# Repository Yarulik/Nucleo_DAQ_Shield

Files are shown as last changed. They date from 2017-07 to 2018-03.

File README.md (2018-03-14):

# Nucleo DAQ Shield
The Nucleo DAQ Shield mixed signal PCB that houses connectors and auxiliary circuitry (buffers, H-bridge, voltage regulators). It allows the STM32 microcontroller to interface with the [Analog Frontend](https://github.com/ColumbiaOpenSourceUltrasound/Analog_Frontend), motor, and other sensors.

### Drawings
Schematic:  
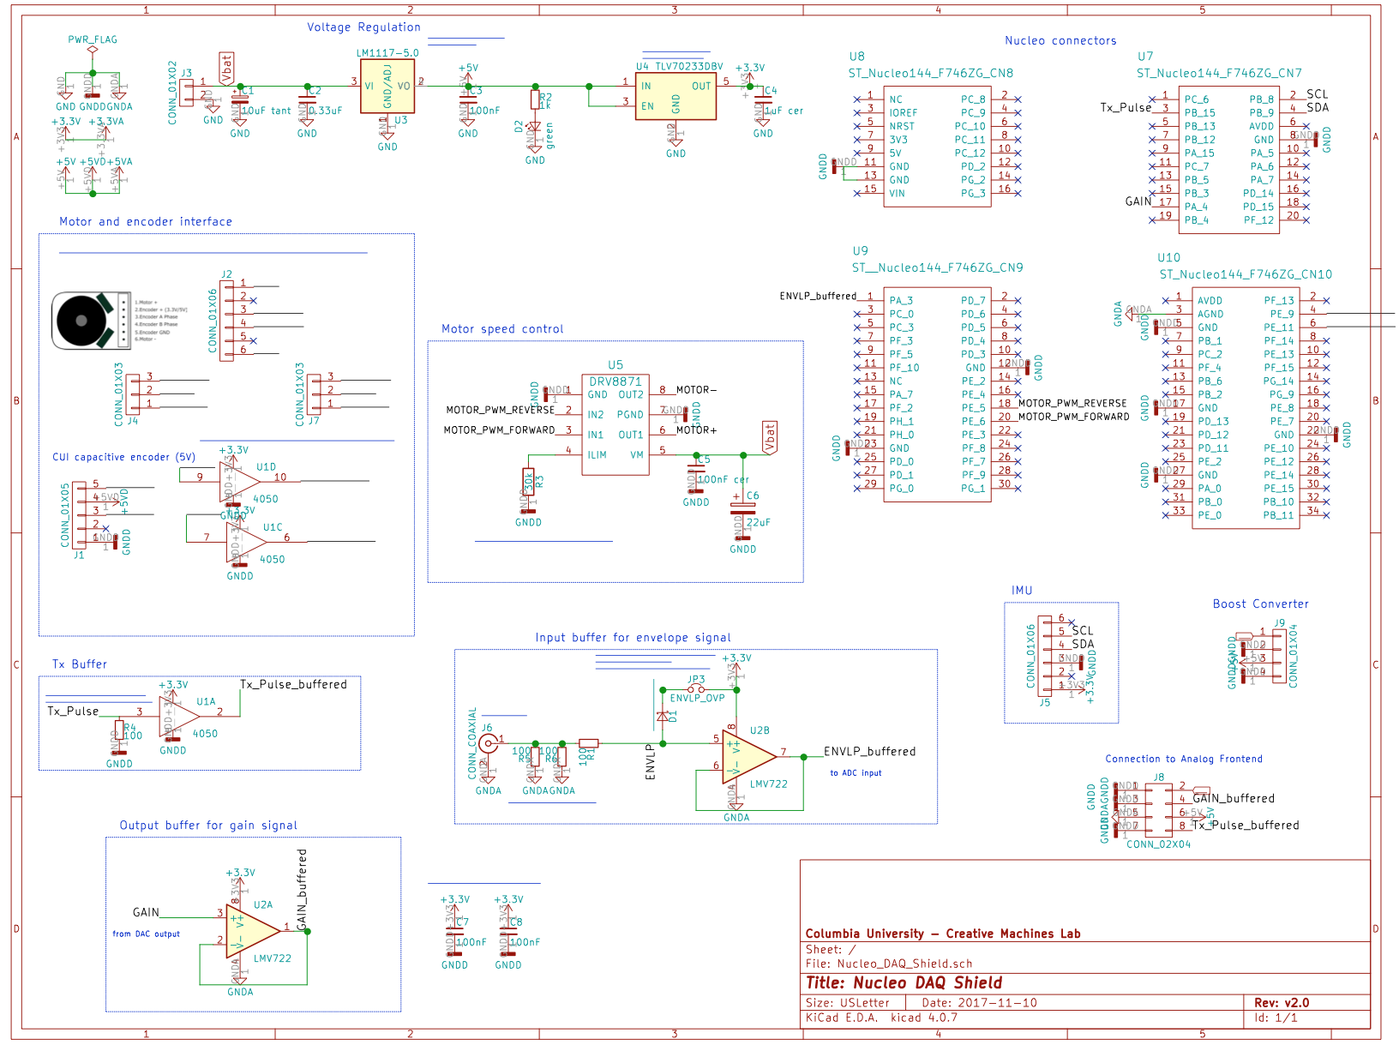
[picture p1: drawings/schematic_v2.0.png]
Schematic
  
See the `drawings` folder for a high-resolution PDF version.

PCB:  
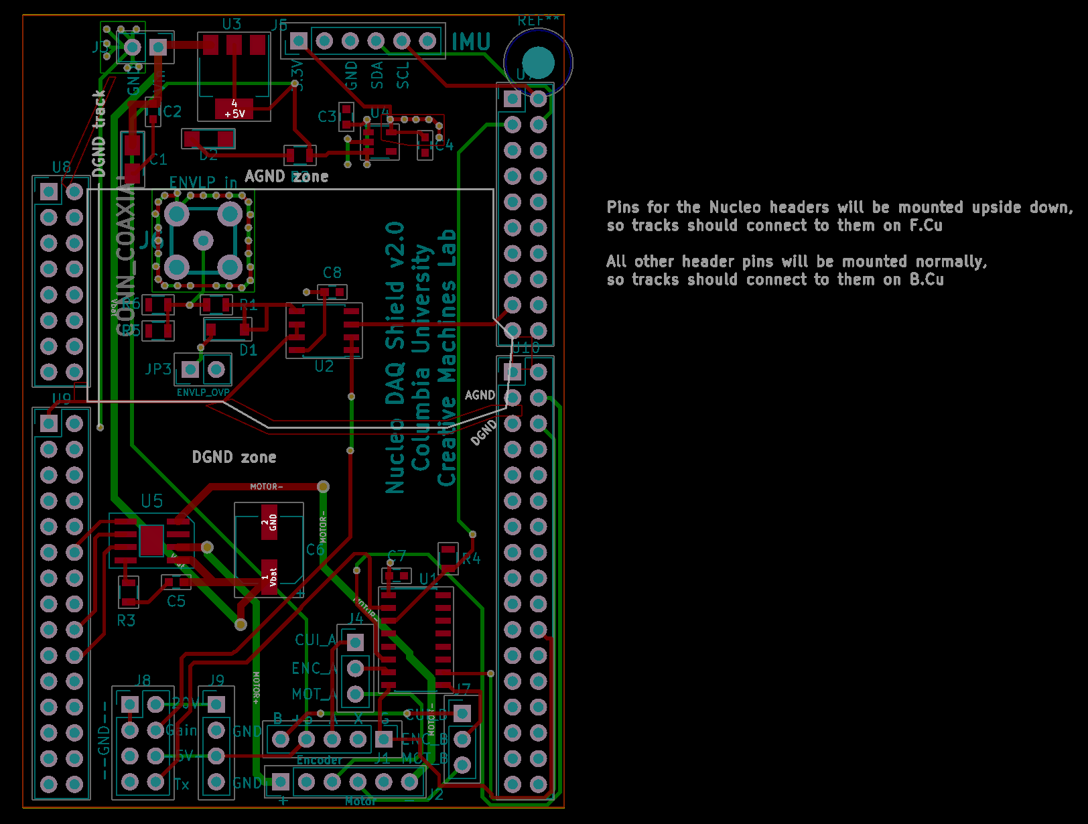
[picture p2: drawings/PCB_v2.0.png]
PCB
  
See the `drawings` folder for a full resolution PDF version, including each layer individually. 

3D view:  
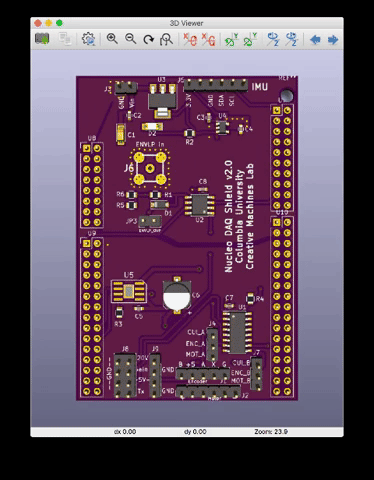
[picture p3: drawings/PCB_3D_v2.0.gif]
3D PCB


### Bill of Materials
See `Nucleo_DAQ_Shield.html`.

### Changelog
* `v1.0` Initial design.
* `v1.2` 
* `v1.3` Changed dimensions to improve manufacturability.
* `v2.0` Replaced several components; added connector for IMU and jumpers to switch between internal/external encoder.

### Credits
Designed by William Meng and Ruoyu Sheng.

The motor control circuitry was adapted from the [Adafruit DRV8871 breakout board](https://learn.adafruit.com/adafruit-drv8871-brushed-dc-motor-driver-breakout/download).

The [Arduino Shield module](https://www.thingiverse.com/thing:9630) by nicholasclewis helped with aligning the header pins.

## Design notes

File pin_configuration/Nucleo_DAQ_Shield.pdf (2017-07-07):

## Nucleo_DAQ_Shield Project Configuration Report

# 1. Description

## 1.1. Project

Project Name | Nucleo_DAQ_Shield
Board Name | No information
Generated with: | STM32CubeMX 4.21.0
Date | 07/07/2017

## 1.2. MCU

MCU Series | STM32F7
MCU Line | STM32F7x6
MCU name | STM32F746ZGTx
MCU Package | LQFP144
MCU Pin number | 144

# 2. Pinout Configuration

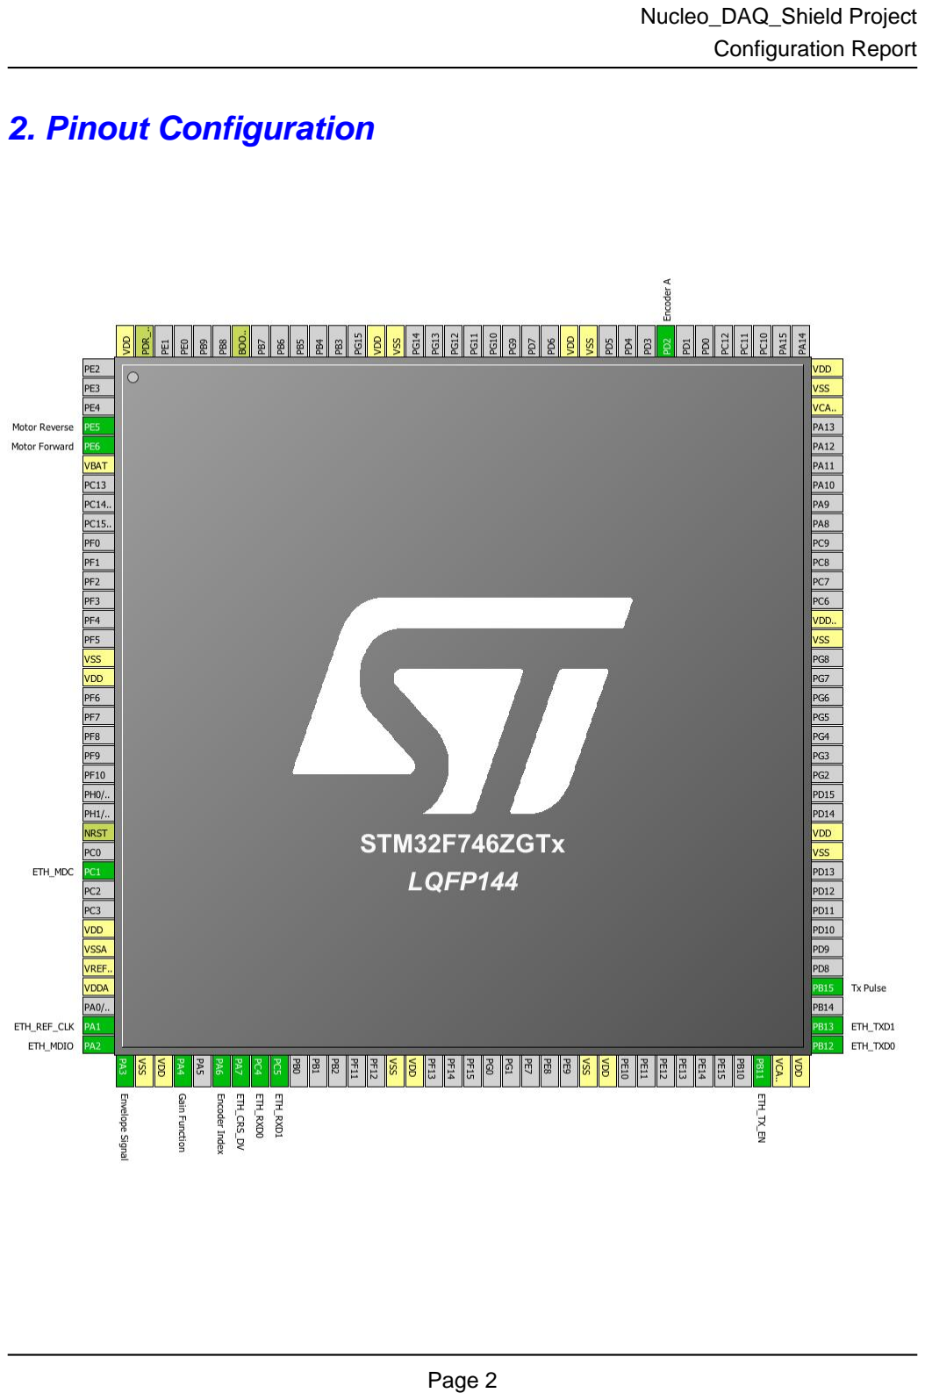
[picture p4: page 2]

# 3. Pins Configuration

Pin Number LQFP144 | Pin Name (function after reset) | Pin Type | Alternate Function(s) | Label
4 | PE5 | I/O | TIM9_CH1 | Motor Reverse
5 | PE6 | I/O | TIM9_CH2 | Motor Forward
6 | VBAT | Power
16 | VSS | Power
17 | VDD | Power
25 | NRST | Reset
27 | PC1 | I/O | ETH_MDC
30 | VDD | Power
31 | VSSA | Power
32 | VREF+ | Power
33 | VDDA | Power
35 | PA1 | I/O | ETH_REF_CLK
36 | PA2 | I/O | ETH_MDIO
37 | PA3 | I/O | ADC1_IN3, ADC2_IN3, ADC3_IN3 | Envelope Signal
38 | VSS | Power
39 | VDD | Power
40 | PA4 | I/O | DAC_OUT1 | Gain Function
42 | PA6 | I/O | TIM3_CH1 | Encoder Index
43 | PA7 | I/O | ETH_CRS_DV
44 | PC4 | I/O | ETH_RXD0
45 | PC5 | I/O | ETH_RXD1
51 | VSS | Power
52 | VDD | Power
61 | VSS | Power
62 | VDD | Power
70 | PB11 | I/O | ETH_TX_EN
71 | VCAP_1 | Power
72 | VDD | Power
73 | PB12 | I/O | ETH_TXD0
74 | PB13 | I/O | ETH_TXD1
76 | PB15 | I/O | TIM12_CH2 | Tx Pulse
83 | VSS | Power
84 | VDD | Power
94 | VSS | Power
95 | VDDUSB | Power

Pin Number LQFP144 | Pin Name (function after reset) | Pin Type | Alternate Function(s) | Label
106 | VCAP_2 | Power
107 | VSS | Power
108 | VDD | Power
116 | PD2 | I/O | TIM3_ETR | Encoder A
120 | VSS | Power
121 | VDD | Power
130 | VSS | Power
131 | VDD | Power
138 | BOOT0 | Boot
143 | PDR_ON | Reset
144 | VDD | Power

# 4. Clock Tree Configuration

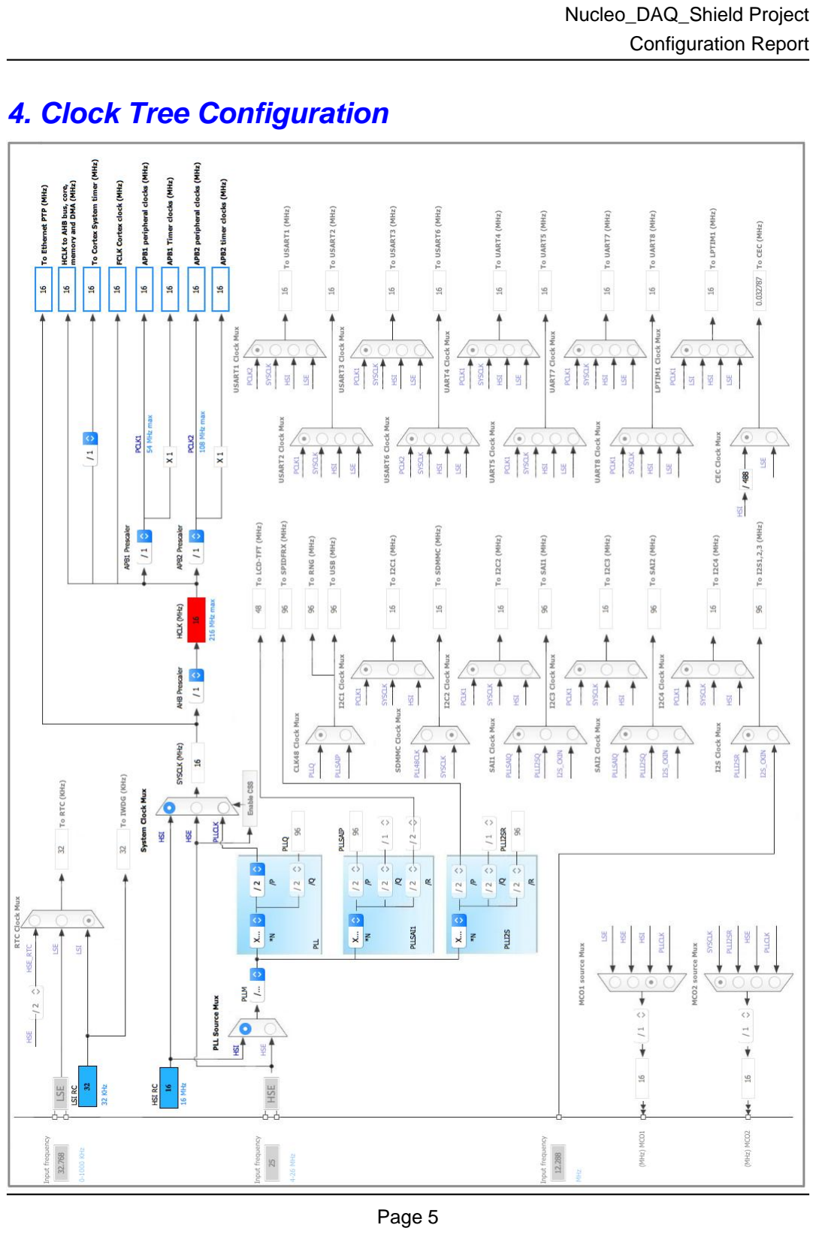
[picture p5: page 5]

# 5. IPs and Middleware Configuration

# 5.1. ADC1

## mode: IN3

## 5.1.1. Parameter Settings:

### ADCs_Common_Settings:

Mode | Independent mode

### ADC_Settings:

Clock Prescaler | PCLK2 divided by 2
Resolution | 12 bits (15 ADC Clock cycles)
Data Alignment | Right alignment
Scan Conversion Mode | Disabled
Continuous Conversion Mode | Disabled
Discontinuous Conversion Mode | Disabled
DMA Continuous Requests | Disabled
End Of Conversion Selection | EOC flag at the end of single channel conversion

### ADC_Regular_ConversionMode:

Number Of Conversion | 1
External Trigger Conversion Source | Regular Conversion launched by software
External Trigger Conversion Edge | None
Rank | 1
Channel | Channel 3
Sampling Time | 3 Cycles

### ADC_Injected_ConversionMode:

Number Of Conversions | 0

### WatchDog:

Enable Analog WatchDog Mode | false

# 5.2. ADC2

## mode: IN3

## 5.2.1. Parameter Settings:

### ADCs_Common_Settings:

Mode | Independent mode

### ADC_Settings:

Clock Prescaler | PCLK2 divided by 2
Resolution | 12 bits (15 ADC Clock cycles)
Data Alignment | Right alignment
Scan Conversion Mode | Disabled
Continuous Conversion Mode | Disabled
Discontinuous Conversion Mode | Disabled
DMA Continuous Requests | Disabled
End Of Conversion Selection | EOC flag at the end of single channel conversion

### ADC_Regular_ConversionMode:

Number Of Conversion | 1
External Trigger Conversion Source | Regular Conversion launched by software
External Trigger Conversion Edge | None
Rank | 1
Channel | Channel 3
Sampling Time | 3 Cycles

### ADC_Injected_ConversionMode:

Number Of Conversions | 0

### WatchDog:

Enable Analog WatchDog Mode | false

# 5.3. ADC3

## mode: IN3

## 5.3.1. Parameter Settings:

### ADCs_Common_Settings:

Mode | Independent mode

### ADC_Settings:

Clock Prescaler | PCLK2 divided by 2
Resolution | 12 bits (15 ADC Clock cycles)
Data Alignment | Right alignment
Scan Conversion Mode | Disabled
Continuous Conversion Mode | Disabled
Discontinuous Conversion Mode | Disabled
DMA Continuous Requests | Disabled
End Of Conversion Selection | EOC flag at the end of single channel conversion

### ADC_Regular_ConversionMode:

Number Of Conversion | 1
External Trigger Conversion Source | Regular Conversion launched by software
External Trigger Conversion Edge | None
Rank | 1
Channel | Channel 3
Sampling Time | 3 Cycles

### ADC_Injected_ConversionMode:

Number Of Conversions | 0

### WatchDog:

Enable Analog WatchDog Mode | false

# 5.4. DAC

## mode: OUT1 Configuration

## 5.4.1. Parameter Settings:

### DAC Out1 Settings:

Output Buffer | Enable
Trigger | None

# 5.5. ETH

## Mode: RMII

## 5.5.1. Parameter Settings:

### Advanced : Ethernet Media Configuration:

Auto Negotiation | Enabled

### General : Ethernet Configuration:

Ethernet MAC Address | 00:80:E1:00:00:00
PHY Address | 1

### Ethernet Basic Configuration:

Rx Mode | Polling Mode
TX IP Header Checksum Computation | By hardware

## 5.5.2. Advanced Parameters:

### External PHY Configuration:

PHY | LAN8742A_PHY_ADDRESS
PHY Address Value | 1
PHY Reset delay these values are based on a 1 ms Systick interrupt | 0x000000FF *
PHY Configuration delay | 0x00000FFF *
PHY Read TimeOut | 0x0000FFFF *
PHY Write TimeOut | 0x0000FFFF *

### Common : External PHY Configuration:

Transceiver Basic Control Register | 0x00 *
Transceiver Basic Status Register | 0x01 *
PHY Reset | 0x8000 *
Select loop-back mode | 0x4000 *
Set the full-duplex mode at 100 Mb/s | 0x2100 *
Set the half-duplex mode at 100 Mb/s | 0x2000 *
Set the full-duplex mode at 10 Mb/s | 0x0100 *
Set the half-duplex mode at 10 Mb/s | 0x0000 *
Enable auto-negotiation function | 0x1000 *
Restart auto-negotiation function | 0x0200 *
Select the power down mode | 0x0800 *
Isolate PHY from MII | 0x0400 *
Auto-Negotiation process completed | 0x0020 *
Valid link established | 0x0004 *
Jabber condition detected | 0x0002 *

### Extended : External PHY Configuration:

PHY special control/status register Offset | 0x10 *
PHY Speed mask | 0x0002 *
PHY Duplex mask | 0x0004 *
PHY Interrupt Source Flag register Offset | 0x000B *
PHY Link down inturrupt | 0x000B *

# 5.6. SYS

## Timebase Source: SysTick

# 5.7. TIM3

## Trigger Source: TI1_ED Clock Source : ETR2

## 5.7.1. Parameter Settings:

### Counter Settings:

Prescaler (PSC - 16 bits value) | 0
Counter Mode | Up
Counter Period (AutoReload Register - 16 bits value ) | 0
Internal Clock Division (CKD) | No Division
auto-reload preload | Disable
Slave Mode Controller | Slave mode disable

### Trigger Output (TRGO) Parameters:

Master/Slave Mode | Disable (no sync between this TIM (Master) and its Slaves
Trigger Event Selection TRGO | Reset (UG bit from TIMx_EGR)

### Clock:

Clock Filter (4 bits value) | 0
Clock Polarity | non inverted
Clock Prescaler | Prescaler not used

### Trigger:

Trigger Filter (4 bits value) | 0

# 5.8. TIM9

## mode: Clock Source Channel1: PWM Generation CH1 Channel2: PWM Generation CH2

## 5.8.1. Parameter Settings:

### Counter Settings:

Prescaler (PSC - 16 bits value) | 0
Counter Mode | Up
Counter Period (AutoReload Register - 16 bits value ) | 0
Internal Clock Division (CKD) | No Division
auto-reload preload | Disable

### Clear Input:

Clear Input Source | Disable

### PWM Generation Channel 1:

Mode | PWM mode 1
Pulse (16 bits value) | 0
Fast Mode | Disable
CH Polarity | High

### PWM Generation Channel 2:

Mode | PWM mode 1
Pulse (16 bits value) | 0
Fast Mode | Disable
CH Polarity | High

# 5.9. TIM12

## Channel2: PWM Generation CH2

## 5.9.1. Parameter Settings:

### Counter Settings:

Prescaler (PSC - 16 bits value) | 0
Counter Mode | Up
Counter Period (AutoReload Register - 16 bits value ) | 0
Internal Clock Division (CKD) | No Division
auto-reload preload | Disable

### Clear Input:

Clear Input Source | Disable

### PWM Generation Channel 2:

Mode | PWM mode 1
Pulse (16 bits value) | 0
Fast Mode | Disable
CH Polarity | High

### * User modified value

# 6. System Configuration

# 6.1. GPIO configuration

IP | Pin | Signal | GPIO mode | GPIO pull/up pull down | Max Speed | User Label
ADC1 | PA3 | ADC1_IN3 | Analog mode | No pull-up and no pull-down | n/a | Envelope Signal
ADC2 | PA3 | ADC2_IN3 | Analog mode | No pull-up and no pull-down | n/a | Envelope Signal
ADC3 | PA3 | ADC3_IN3 | Analog mode | No pull-up and no pull-down | n/a | Envelope Signal
DAC | PA4 | DAC_OUT1 | Analog mode | No pull-up and no pull-down | n/a | Gain Function
| | | | | *
| PA1 | ETH_REF_CLK | Alternate Function Push Pull | No pull-up and no pull-down | Very High *
| PA2 | ETH_MDIO | Alternate Function Push Pull | No pull-up and no pull-down | Very High *
| PA7 | ETH_CRS_DV | Alternate Function Push Pull | No pull-up and no pull-down | Very High *
| PC4 | ETH_RXD0 | Alternate Function Push Pull | No pull-up and no pull-down | Very High *
| PC5 | ETH_RXD1 | Alternate Function Push Pull | No pull-up and no pull-down | Very High *
| PB11 | ETH_TX_EN | Alternate Function Push Pull | No pull-up and no pull-down | Very High *
| PB12 | ETH_TXD0 | Alternate Function Push Pull | No pull-up and no pull-down | Very High *
| PB13 | ETH_TXD1 | Alternate Function Push Pull | No pull-up and no pull-down | Very High *
TIM3 | PA6 | TIM3_CH1 | Alternate Function Push Pull | No pull-up and no pull-down | Low | Encoder Index
| PD2 | TIM3_ETR | Alternate Function Push Pull | No pull-up and no pull-down | Low | Encoder A
TIM9 | PE5 | TIM9_CH1 | Alternate Function Push Pull | No pull-up and no pull-down | Low | Motor Reverse
| PE6 | TIM9_CH2 | Alternate Function Push Pull | No pull-up and no pull-down | Low | Motor Forward
TIM12 | PB15 | TIM12_CH2 | Alternate Function Push Pull | No pull-up and no pull-down | Low | Tx Pulse
ETH | PC1 | ETH_MDC | Alternate Function Push Pull | No pull-up and no pull-down | Very High

# 6.2. DMA configuration

## nothing configured in DMA service

# 6.3. NVIC configuration

Interrupt Table | Enable | Preenmption Priority | SubPriority
Non maskable interrupt | true | 0 | 0
Hard fault interrupt | true | 0 | 0
Memory management fault | true | 0 | 0
Pre-fetch fault, memory access fault | true | 0 | 0
Undefined instruction or illegal state | true | 0 | 0
System service call via SWI instruction | true | 0 | 0
Debug monitor | true | 0 | 0
Pendable request for system service | true | 0 | 0
System tick timer | true | 0 | 0
PVD interrupt through EXTI line 16 | unused
Flash global interrupt | unused
RCC global interrupt | unused
ADC1, ADC2 and ADC3 global interrupts | unused
TIM1 break interrupt and TIM9 global interrupt | unused
TIM3 global interrupt | unused
TIM8 break interrupt and TIM12 global interrupt | unused
TIM6 global interrupt, DAC1 and DAC2 underrun error interrupts | unused
Ethernet global interrupt | unused
Ethernet wake-up interrupt through EXTI line 19 | unused
FPU global interrupt | unused

### * User modified value

# 7. Power Consumption Calculator report

### 7.1. Microcontroller Selection

Series | STM32F7
Line | STM32F7x6
MCU | STM32F746ZGTx
Datasheet | 027590_Rev4

### 7.2. Parameter Selection

Temperature | 25
Vdd | 3.3

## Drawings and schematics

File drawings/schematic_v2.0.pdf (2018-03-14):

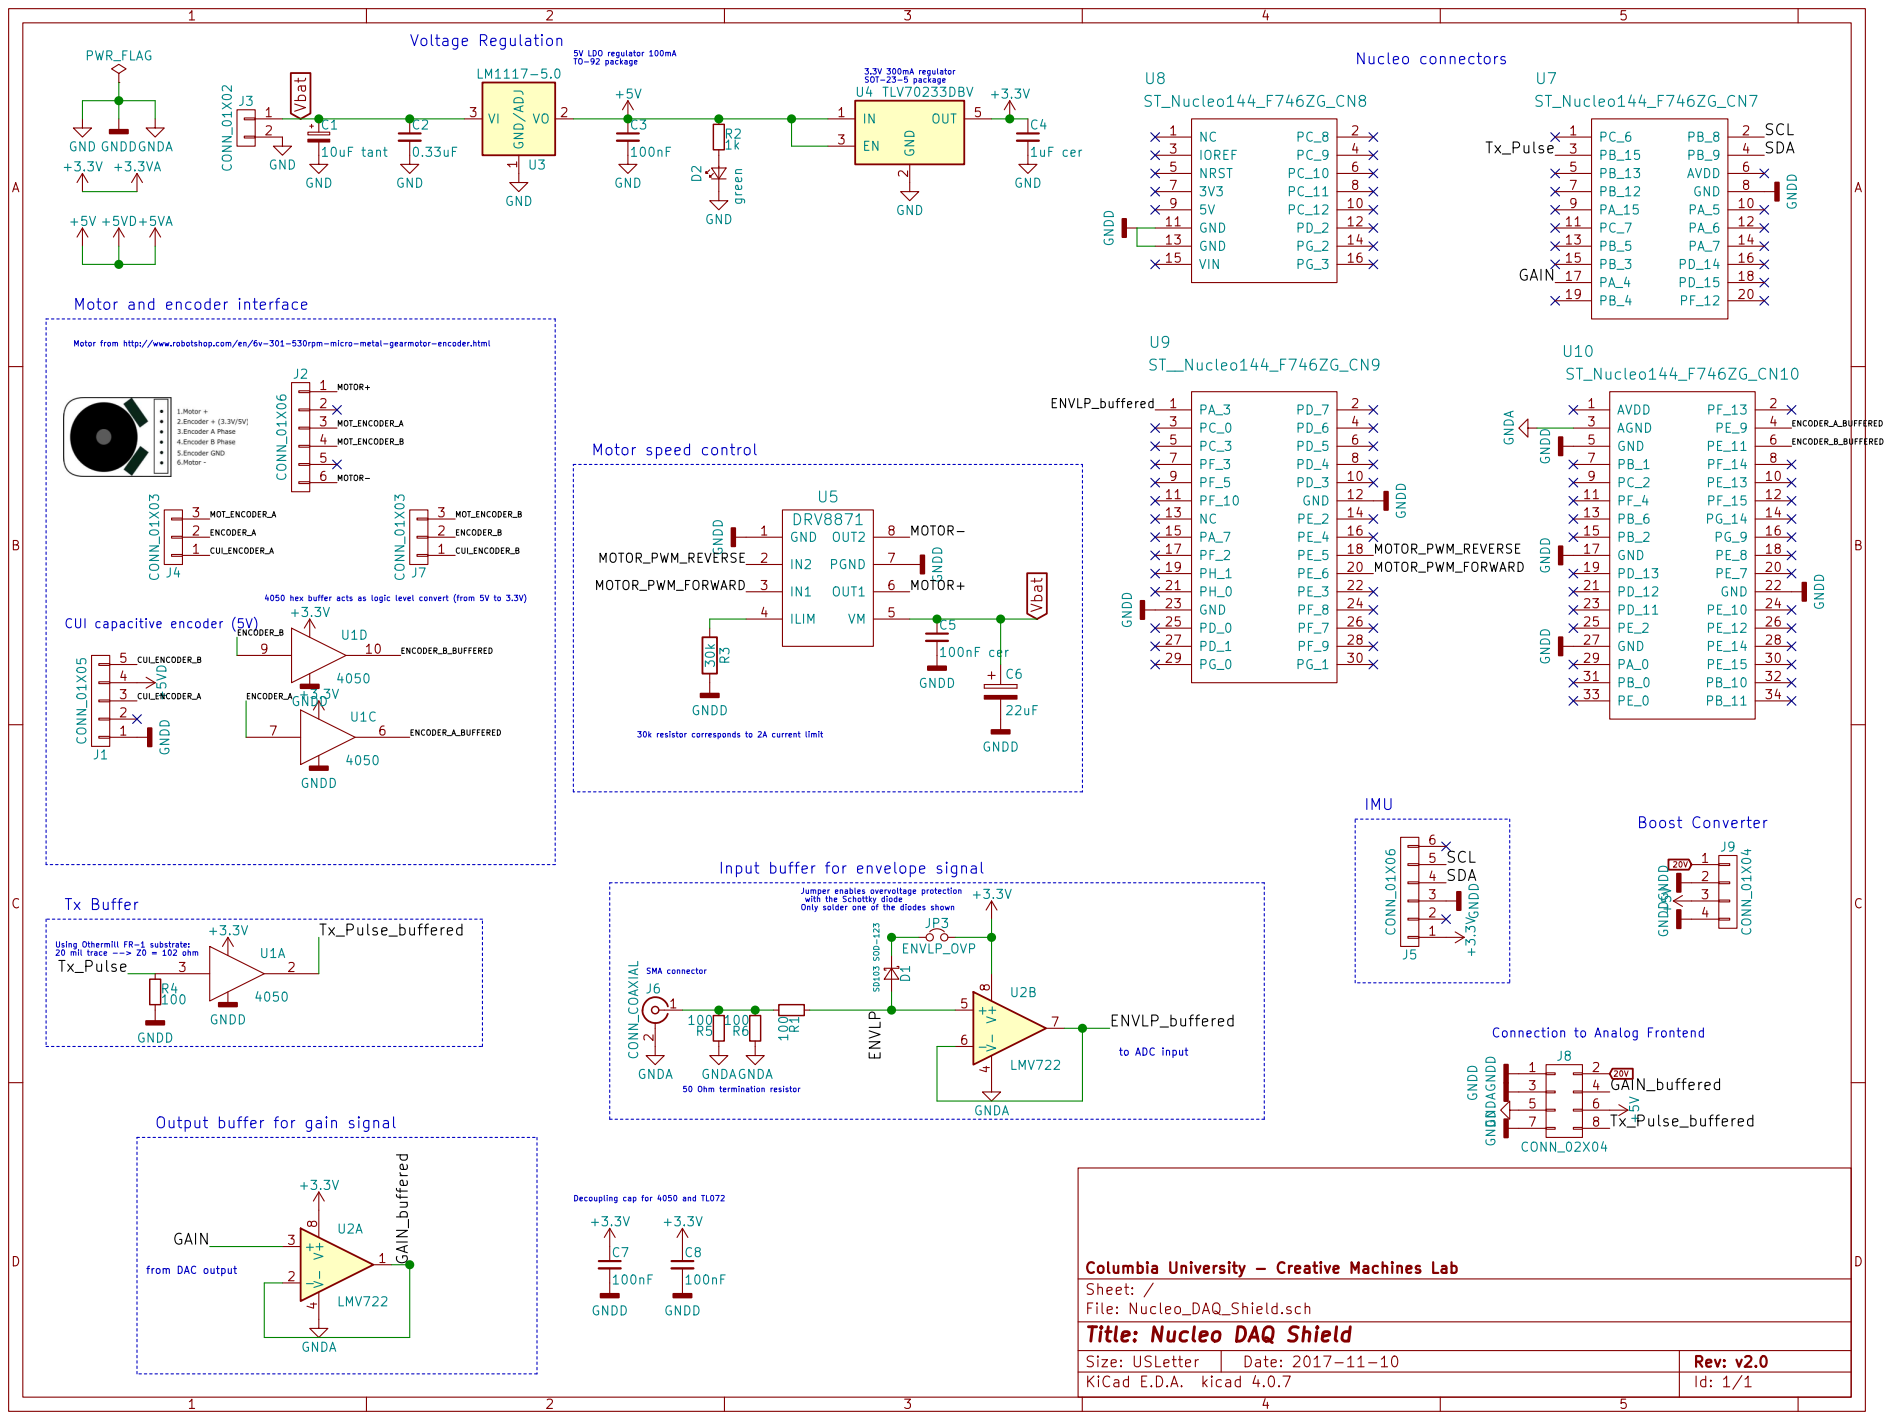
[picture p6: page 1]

3.3V 300mA regulator SOT-23-5 package GND

with the Schottky diode Only solder one of the diodes shown Motor and encoder interface

Motor from http://www.robotshop.com/en/6v-301-530rpm-micro-metal-gearmotor-encoder.html MOTOR+ MOTOR-

30k resistor corresponds to 2A current limit Tx_Pulse

Input buffer for envelope signal

Jumper enables overvoltage protection

Connection to Analog Frontend

Output buffer for gain signal

Decoupling cap for 4050 and TL072C8

File: Nucleo_DAQ_Shield.sch Sheet: / Columbia University - Creative Machines Lab V- 4 V+

Id: 1/1 Title: Nucleo DAQ Shield

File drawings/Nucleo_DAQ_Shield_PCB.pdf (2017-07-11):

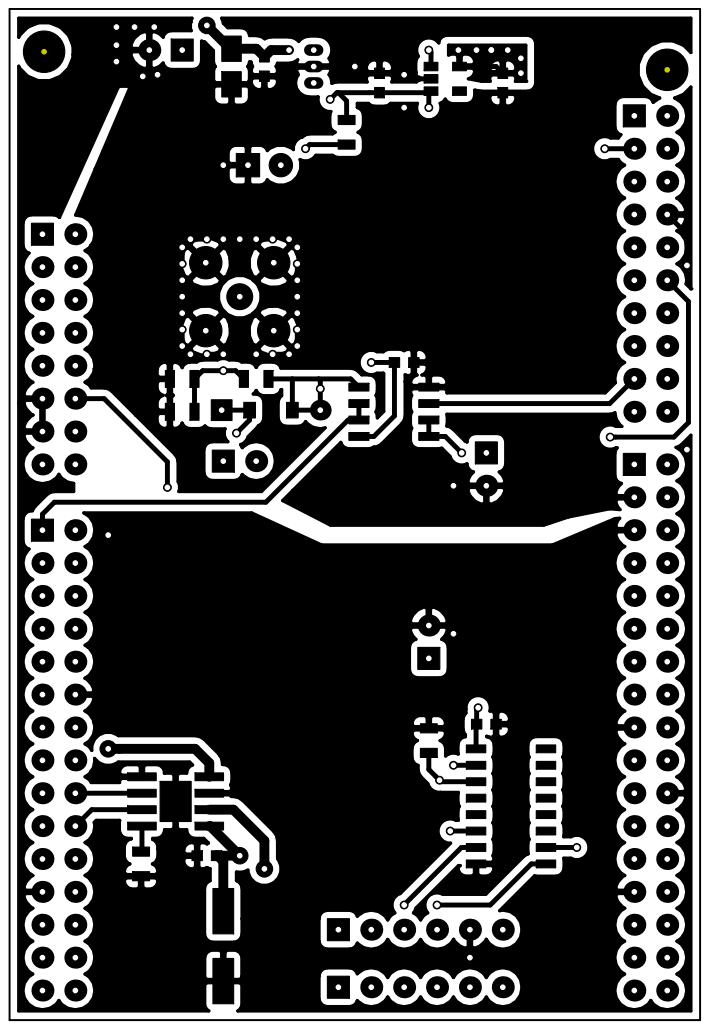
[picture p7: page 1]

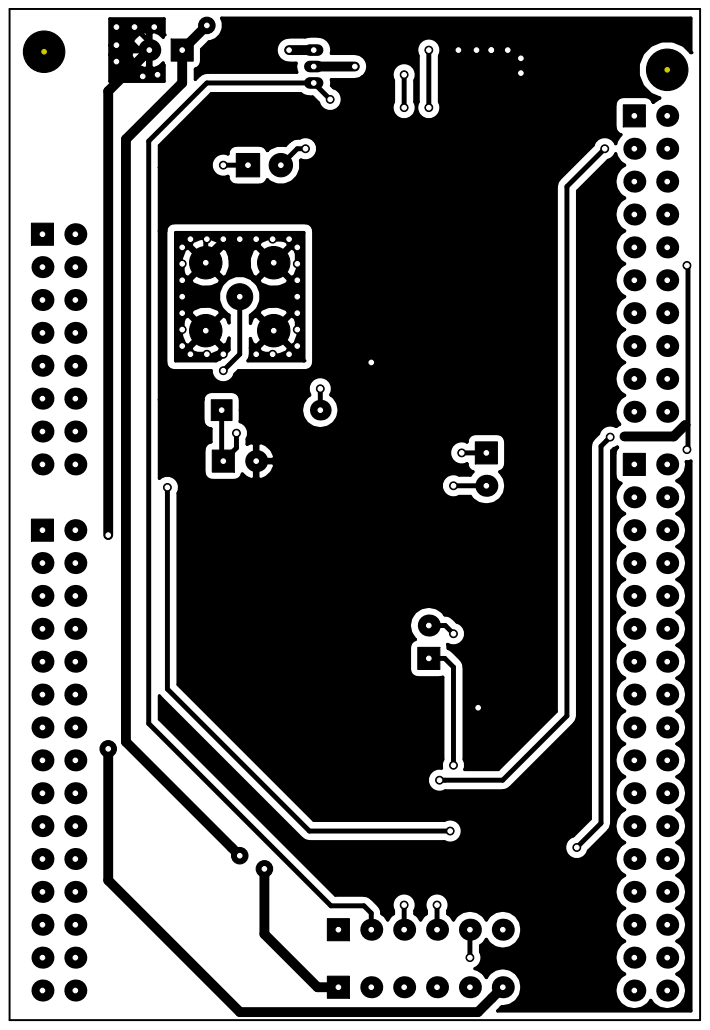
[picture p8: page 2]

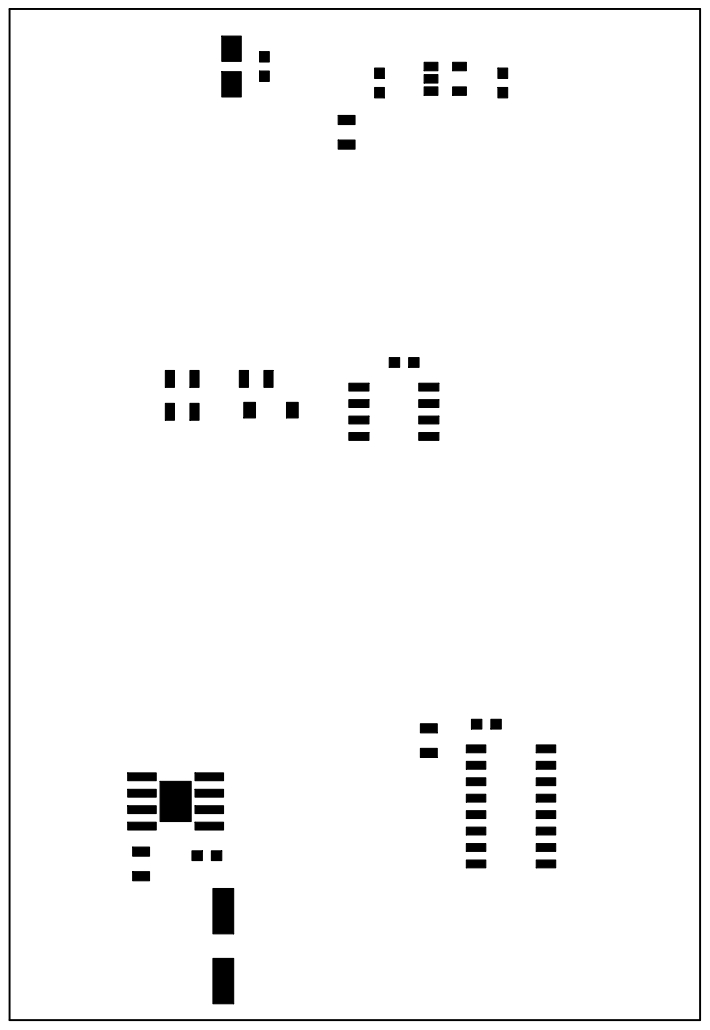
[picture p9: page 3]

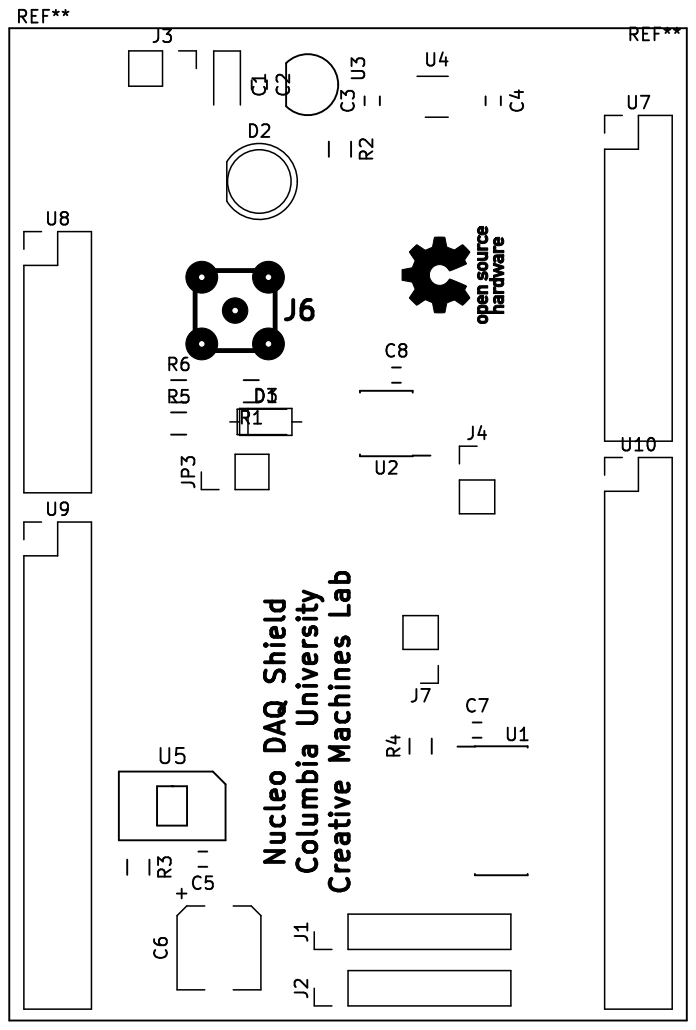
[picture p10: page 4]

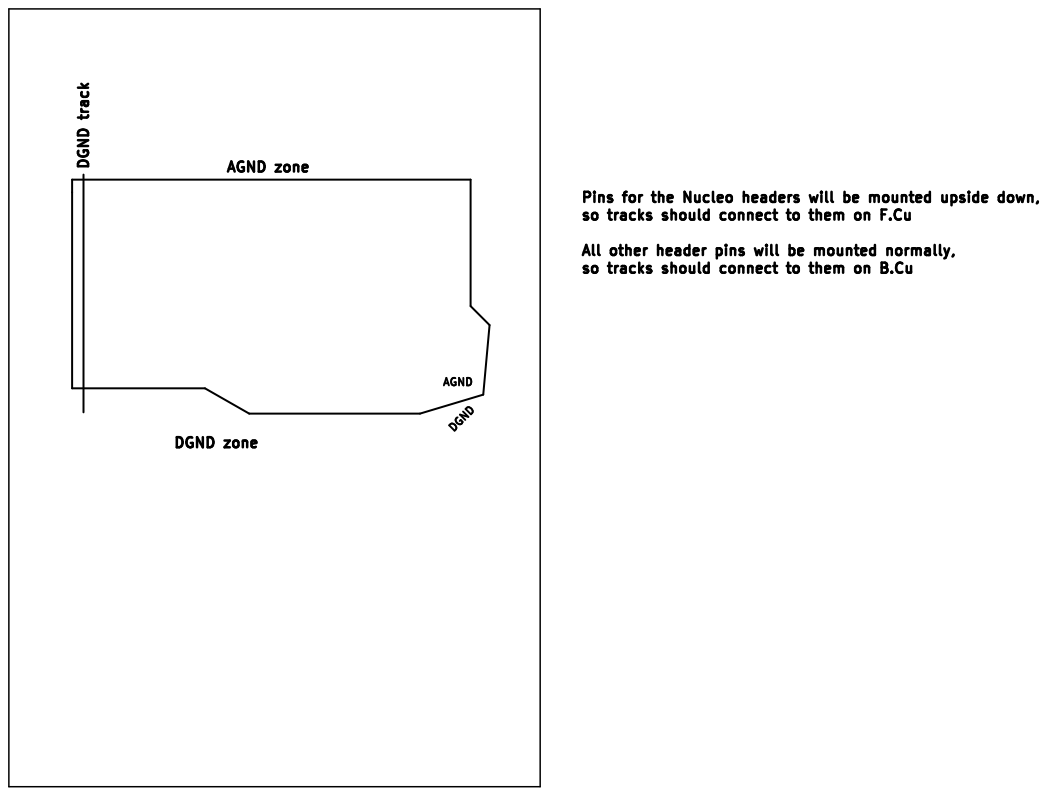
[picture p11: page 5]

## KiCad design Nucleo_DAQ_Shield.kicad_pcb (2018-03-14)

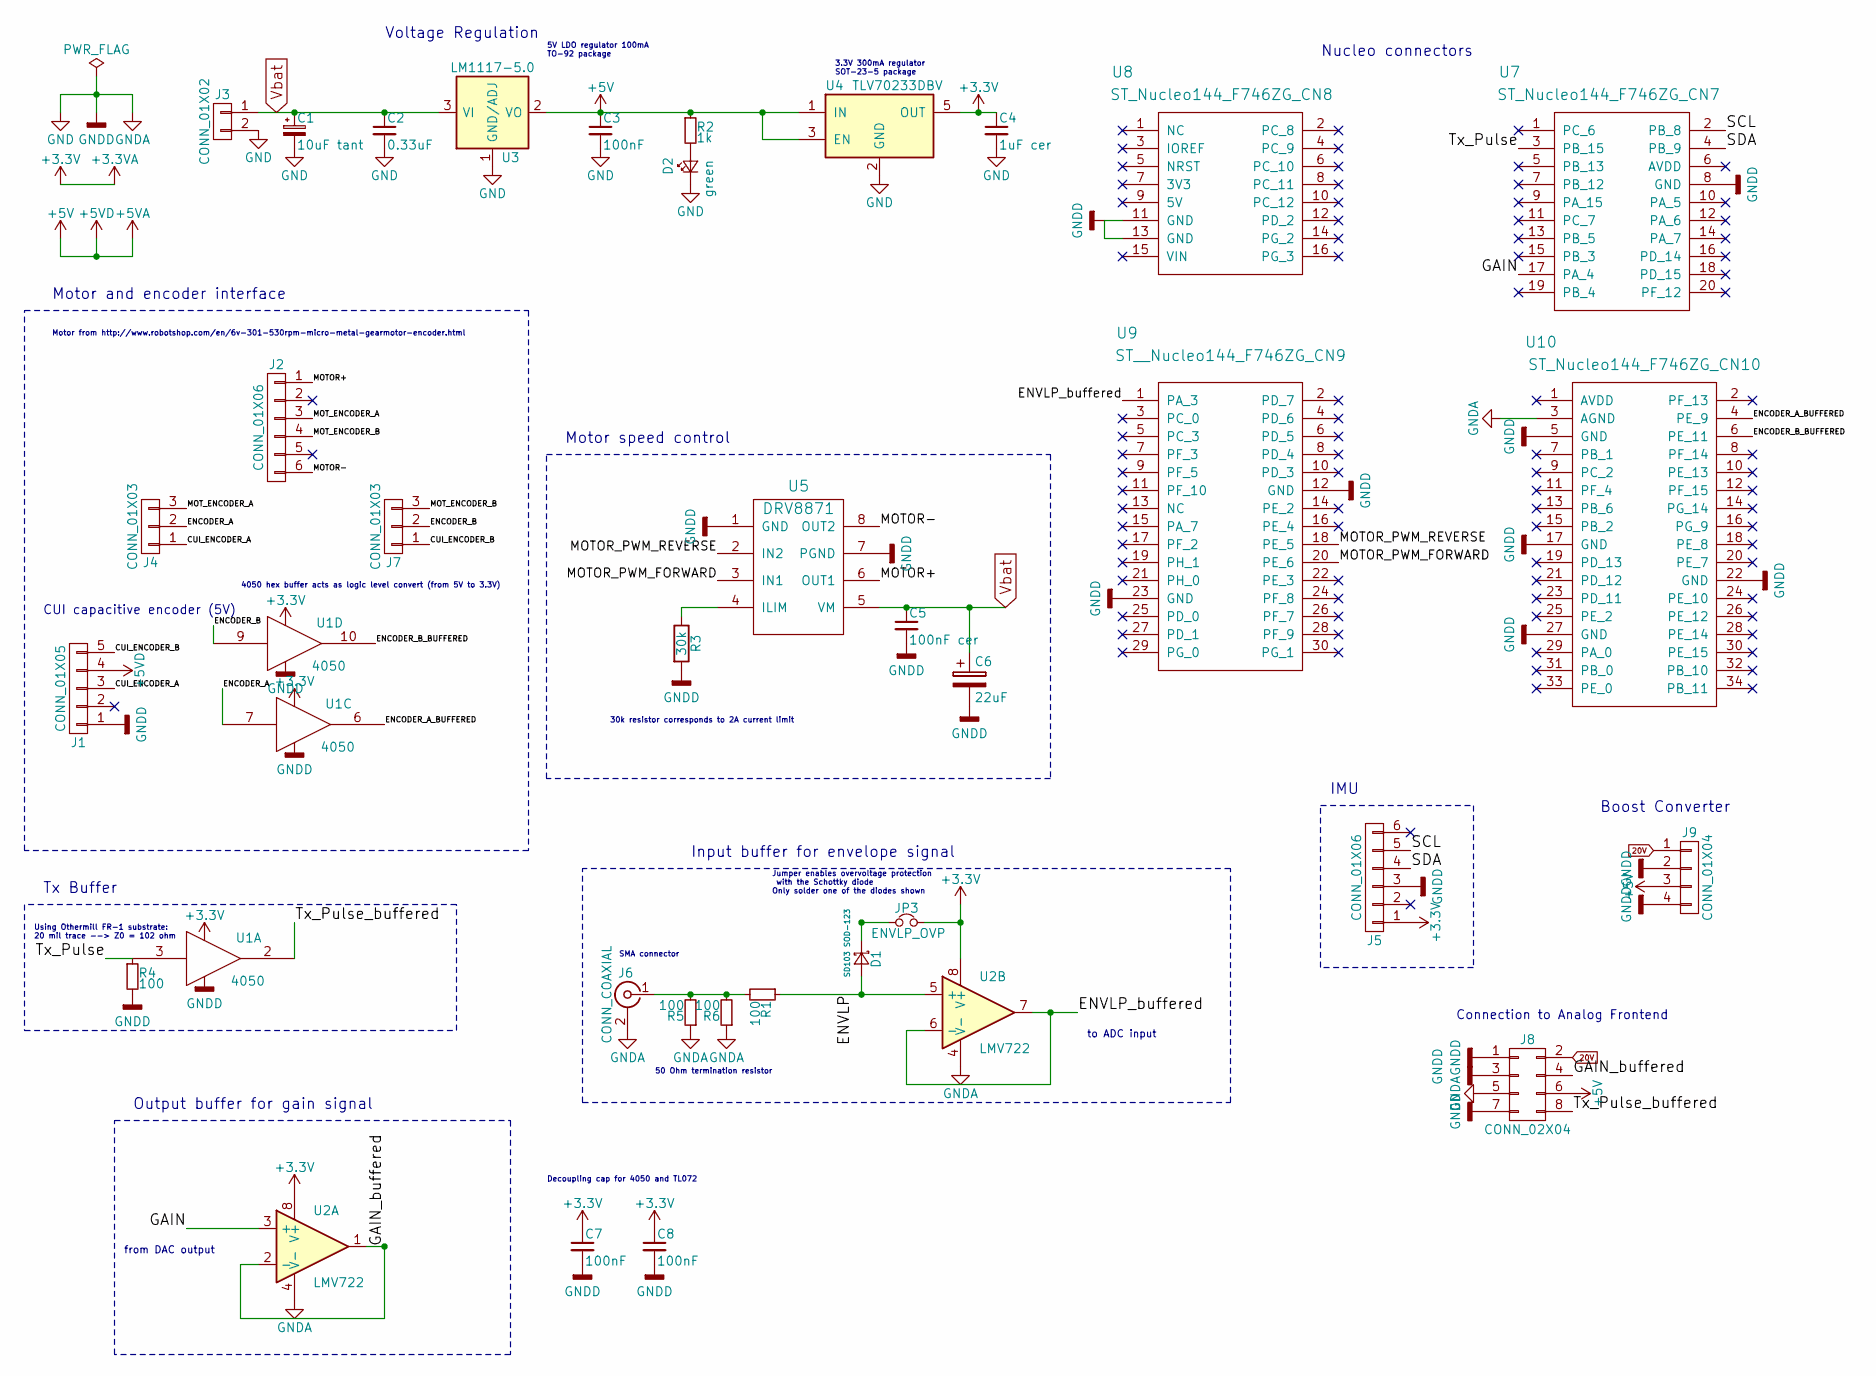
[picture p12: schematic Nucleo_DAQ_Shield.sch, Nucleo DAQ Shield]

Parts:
C1: 10uF tant; CP_Tantalum_Case-A_EIA-3216-18_Reflow
C2: 0.33uF; C_0603
C3, C7, C8: 100nF; C_0603
C4: 1uF cer; C_0603
C5: 100nF cer; C_0603
C6: 22uF; CP_Elec_6.3x5.8
D1: SD103 SOD-123; D_SOD-123
D2: green; LED_1206
J1: CONN_01X05; Pin_Header_Straight_1x05_Pitch2.54mm
J2, J5: CONN_01X06; Pin_Header_Straight_1x06_Pitch2.54mm
J3: CONN_01X02; Pin_Header_Straight_1x02_Pitch2.54mm
J4, J7: CONN_01X03; Pin_Header_Straight_1x03_Pitch2.54mm
J6: CONN_COAXIAL; SMA_uxcell
J8: CONN_02X04; Pin_Header_Straight_2x04_Pitch2.54mm
J9: CONN_01X04; Pin_Header_Straight_1x04_Pitch2.54mm
JP3: ENVLP_OVP; Pin_Header_Straight_1x02_Pitch2.54mm
R1, R4, R5, R6: 100; R_0805
R2: 1k; R_0805
R3: 30k; R_0805
U1: 4050; SOIC-16_3.9x9.9mm_Pitch1.27mm
U2: LMV722; SOIC-8_3.9x4.9mm_Pitch1.27mm
U3: LM1117-5.0; SOT-223
U4: TLV70233DBV; SOT-23-5
U5: DRV8871; SOIC-8_PowerPad
U7: ST_Nucleo144_F746ZG_CN7; Pin_Header_Straight_2x10_Pitch2.54mm
U8: ST_Nucleo144_F746ZG_CN8; Pin_Header_Straight_2x08_Pitch2.54mm
U9: ST__Nucleo144_F746ZG_CN9; Pin_Header_Straight_2x15_Pitch2.54mm
U10: ST_Nucleo144_F746ZG_CN10; Pin_Header_Straight_2x17_Pitch2.54mm

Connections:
20V: J8.2, J9.1
+3.3VA: C4.1, C7.1, C8.1, J5.1, JP3.2, U1.1 (VCC), U2.8 (V+), U4.5 (OUT)
+5V: C3.1, J1.4, J8.6, J9.3, R2.1, U3.2 (VO), U3.4 (VO), U4.1 (IN), U4.3 (EN)
/CUI_ENCODER_A: J1.3, J4.1
/CUI_ENCODER_B: J1.5, J7.1
/ENCODER_A: J4.2, U1.7
/ENCODER_A_BUFFERED: U1.6, U10.4 (PE_9)
/ENCODER_B: J7.2, U1.9
/ENCODER_B_BUFFERED: U1.10, U10.6 (PE_11)
/ENVLP: D1.2 (A), R1.1, U2.5 (+)
/ENVLP_buffered: U2.6 (-), U2.7, U9.1 (PA_3)
/GAIN: U2.3 (+), U7.17 (PA_4)
/GAIN_buffered: J8.4, U2.1, U2.2 (-)
/MOTOR+: J2.1, U5.6 (OUT1)
/MOTOR-: J2.6, U5.8 (OUT2)
/MOTOR_PWM_FORWARD: U5.3 (IN1), U9.20 (PE_6)
/MOTOR_PWM_REVERSE: U5.2 (IN2), U9.18 (PE_5)
/MOT_ENCODER_A: J2.3, J4.3
/MOT_ENCODER_B: J2.4, J7.3
/SCL: J5.5, U7.2 (PB_8)
/SDA: J5.4, U7.4 (PB_9)
/Tx_Pulse: R4.1, U1.3, U7.3 (PB_15)
/Tx_Pulse_buffered: J8.8, U1.2
GND: C1.2, C2.2, C3.2, C4.2, C5.2, C6.2, C7.2, C8.2, D2.1 (K), J1.1, J3.2, J5.3, J6.2 (Ext), J8.1, J8.3, J8.5, J8.7, J9.2, J9.4, R3.2, R4.2, R5.1, R6.1, U1.8 (VSS), U2.4 (V-), U3.1 (GND/ADJ), U4.2 (GND), U5.1 (GND), U5.7 (PGND), U7.8 (GND), U8.11 (GND), U8.13 (GND), U9.12 (GND), U9.23 (GND), U10.3 (AGND), U10.5 (GND), U10.17 (GND), U10.22 (GND), U10.27 (GND)
unnamed: D1.1 (K), JP3.1
unnamed: D2.2 (A), R2.2
unnamed: J6.1 (In), R1.2, R5.2, R6.2
unnamed: R3.1, U5.4 (ILIM)
Vbat: C1.1, C2.1, C5.1, C6.1, J3.1, U3.3 (VI), U5.5 (VM)

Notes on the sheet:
Output buffer for gain signal
Input buffer for envelope signal
from DAC output
to ADC input
Motor from http://www.robotshop.com/en/6v-301-530rpm-micro-metal-gearmotor-encoder.html
CUI capacitive encoder (5V)
3.3V 300mA regulator SOT-23-5 package
Motor speed control
Nucleo connectors
Jumper enables overvoltage protection with the Schottky diode Only solder one of the diodes shown
Motor and encoder interface
50 Ohm termination resistor
4050 hex buffer acts as logic level convert (from 5V to 3.3V)
30k resistor corresponds to 2A current limit
Tx Buffer
Voltage Regulation
Decoupling cap for 4050 and TL072
Using Othermill FR-1 substrate: 20 mil trace --> Z0 = 102 ohm
SMA connector
5V LDO regulator 100mA TO-92 package
IMU
Boost Converter
Connection to Analog Frontend

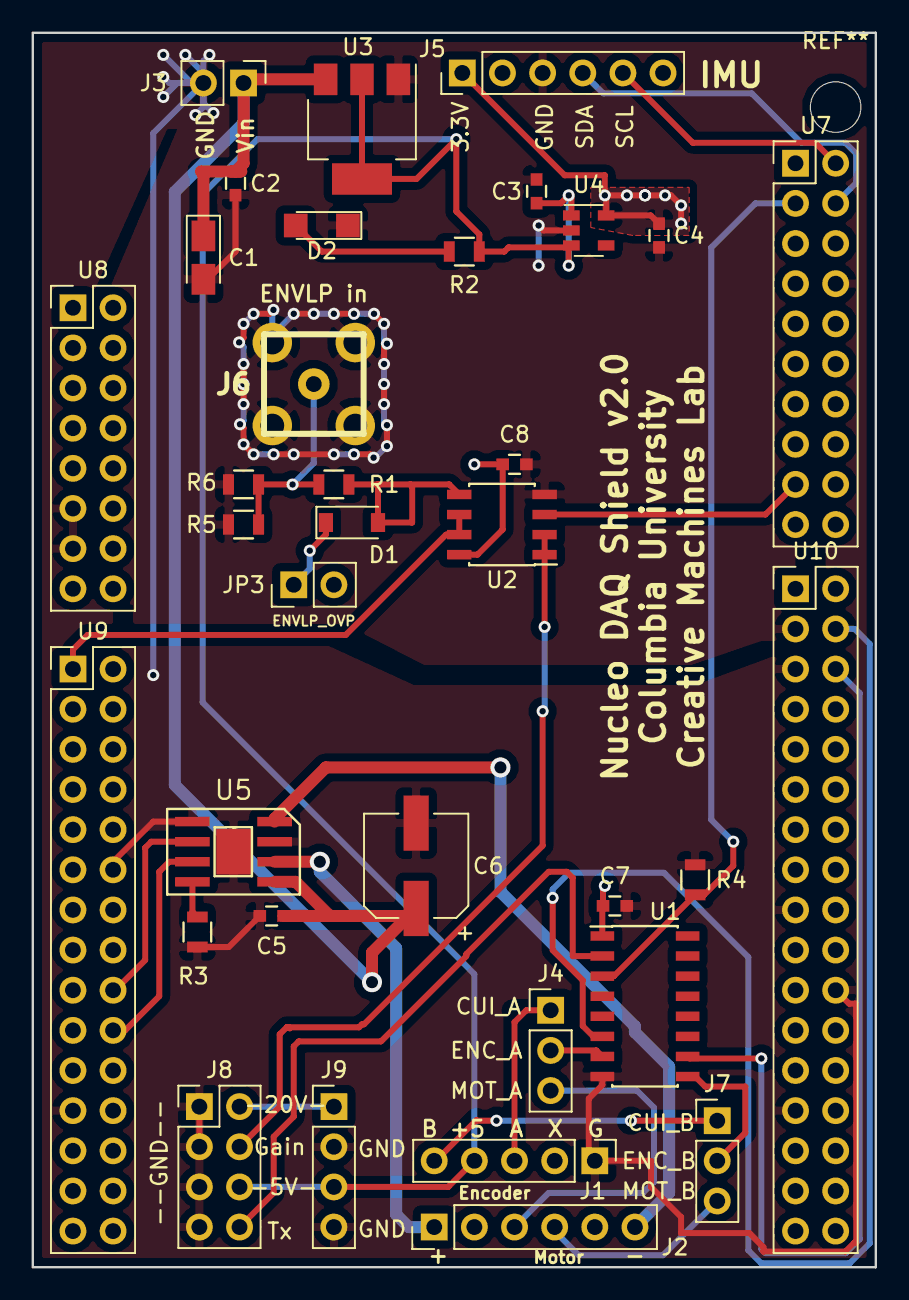
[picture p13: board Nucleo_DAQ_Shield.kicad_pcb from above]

Board: 2 copper layers, 53.3 x 78.1 mm, 35 parts (0 on the bottom side), 29 nets.

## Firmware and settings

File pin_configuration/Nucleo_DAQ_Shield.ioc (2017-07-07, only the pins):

Mcu.UserName=STM32F746ZGTx
PA1.Signal=ETH_REF_CLK
PA2.Signal=ETH_MDIO
PA3.GPIO_Label=Envelope Signal
PA3.Signal=ADCx_IN3
PA4.GPIO_Label=Gain Function
PA4.Signal=COMP_DAC1_group
PA6.GPIO_Label=Encoder Index
PA6.Signal=S_TIM3_CH1
PA7.Signal=ETH_CRS_DV
PB11.Signal=ETH_TX_EN
PB12.Signal=ETH_TXD0
PB13.Signal=ETH_TXD1
PB15.GPIO_Label=Tx Pulse
PB15.Signal=S_TIM12_CH2
PC1.Signal=ETH_MDC
PC4.Signal=ETH_RXD0
PC5.Signal=ETH_RXD1
PD2.GPIO_Label=Encoder A
PD2.Signal=S_TIM3_ETR
PE5.GPIO_Label=Motor Reverse
PE5.Signal=S_TIM9_CH1
PE6.GPIO_Label=Motor Forward
PE6.Signal=S_TIM9_CH2

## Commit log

2017-07-03 Started designing Nucleo DAQ Shield
    [Nucleo_DAQ_Shield.kicad_pcb, Nucleo_DAQ_Shield.sch]
2017-07-03 Added analog buffers and connection for motor/encoder
    [Nucleo_DAQ_Shield.sch]
2017-07-05 Added voltage regulators and updated encoder connections
    [Nucleo_DAQ_Shield.sch]
2017-07-05 Added Overvoltage Protection for envelope input buffer and jumpers to choose between motor encoder vs CUI encoder
    [Nucleo_DAQ_Shield.sch]
2017-07-05 Added H-bridge for motor speed control
    [Nucleo_DAQ_Shield.sch]
2017-07-07 Added reference diagram for the electrical characteristics of the ADC input
    [Nucleo_DAQ_Shield.sch]
2017-07-07 Mapped out pin assignments and configurations using STM32CubeMX and generated a report file
2017-07-08 Library for Nucleo F746ZG connector symbols
2017-07-10 Added Nucleo connectors to schematic and started associating footprints
    [Nucleo_DAQ_Shield.sch]
2017-07-10 Updated Nucleo connector symbols
2017-07-10 Updated Nucleo connectors in schematic
    [Nucleo_DAQ_Shield.sch]
2017-07-10 Reorganized schematic
    [Nucleo_DAQ_Shield.sch]
2017-07-10 Associated all footprints in CvPCB
    [Nucleo_DAQ_Shield.sch]
2017-07-10 Aligned connectors to Arduino shield layout
    [Nucleo_DAQ_Shield.kicad_pcb, Nucleo_DAQ_Shield.sch]
2017-07-10 Rough placement of all components
    [Nucleo_DAQ_Shield.kicad_pcb, Nucleo_DAQ_Shield.sch]
2017-07-11 Some progress on routing
    [Nucleo_DAQ_Shield.kicad_pcb, Nucleo_DAQ_Shield.sch]
2017-07-11 Mostly isolated AGND and DGND planes and fully routed analog portion; partially routed digital side
    [Nucleo_DAQ_Shield.kicad_pcb, Nucleo_DAQ_Shield.sch]
2017-07-11 Removed extraneous parts and finished PCB layout
    [Nucleo_DAQ_Shield.kicad_pcb, Nucleo_DAQ_Shield.sch]
2017-07-11 Finalized v1.0 of PCB design
    [Nucleo_DAQ_Shield.kicad_pcb, Nucleo_DAQ_Shield.sch]
2017-07-11 Gerbers and drawings for v1.0
    [Nucleo_DAQ_Shield.kicad_pcb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]
2017-07-11 Added through hold Schottky diode as an alternative to SOD-123 Schottky diode
    [Nucleo_DAQ_Shield.kicad_pcb, Nucleo_DAQ_Shield.sch]
2017-07-11 SOIC-8 PowerPad footprint for the DRV8871 motor driver chip
2017-07-11 Nucleo DAQ Shield v1.2
    [Nucleo_DAQ_Shield.kicad_pcb, Nucleo_DAQ_Shield.sch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]
2017-07-12 Added stencil file with 7mil mask to paste clearance
    [Nucleo_DAQ_Shield.kicad_pcb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]
2017-07-12 Added BOM file
2017-07-12 Stencil now has 10mil mask to paste clearance; Nucleo header pins have been flipped in 3D view
    [Nucleo_DAQ_Shield.kicad_pcb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]
2017-07-13 Swapped out TO-92 footprint to make it larger; refined separation between AGND and DGND
    [Nucleo_DAQ_Shield.kicad_pcb, Nucleo_DAQ_Shield.sch]
2017-07-13 Updated all vias to have at least 15 mil ring thickness
    [Nucleo_DAQ_Shield.kicad_pcb]
2017-07-13 Shrunk PowerPad size on the DRV8871's footprint
    [Nucleo_DAQ_Shield.kicad_pcb]
2017-07-13 v1.3 Gerbers
    [Nucleo_DAQ_Shield.kicad_pcb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]
2017-07-18 BOM for Analog Frontend PCB v1.3
    [Nucleo_DAQ_Shield.sch]
2017-07-20 Added silkscreen labels on Nucleo DAQ Shield PCB
    [Nucleo_DAQ_Shield.kicad_pcb]
2017-10-19 Analog BOM & Nucleo pins added
    [Nucleo_DAQ_Shield.kicad_pcb, Nucleo_DAQ_Shield.sch]
2017-10-25 nucleo board updated
    [Nucleo_DAQ_Shield.kicad_pcb, Nucleo_DAQ_Shield.sch]
2017-11-07 Updated IMU connector and encoder pins
    [Nucleo_DAQ_Shield.kicad_pcb, Nucleo_DAQ_Shield.sch]
2017-11-07 Q2 footprint change, connect ground plane
    [Nucleo_DAQ_Shield.kicad_pcb]
2017-11-08 Necleo board encoder switch
    [Nucleo_DAQ_Shield.kicad_pcb, Nucleo_DAQ_Shield.sch]
2017-11-10 SMT LED & regulator
2017-11-10 v2.0
    Fixed pin assignments for SDA and SCL
    Silkscreen labels for IMU pins
    Reorganized schematic
    Repositioned silkscreen labels to improve readability
    [Nucleo_DAQ_Shield.kicad_pcb, Nucleo_DAQ_Shield.sch]
2017-12-01 connector footprint change
2018-03-14 Corrected header pin orientation and added v2.0 drawings.
    [Nucleo_DAQ_Shield.kicad_pcb]
2018-03-14 Updated README and screenshot of PCB
